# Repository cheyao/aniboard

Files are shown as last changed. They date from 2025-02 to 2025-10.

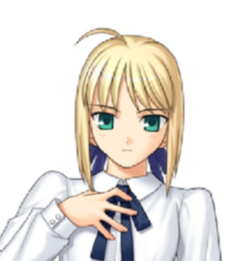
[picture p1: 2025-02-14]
PCB/art/saber-serious.png

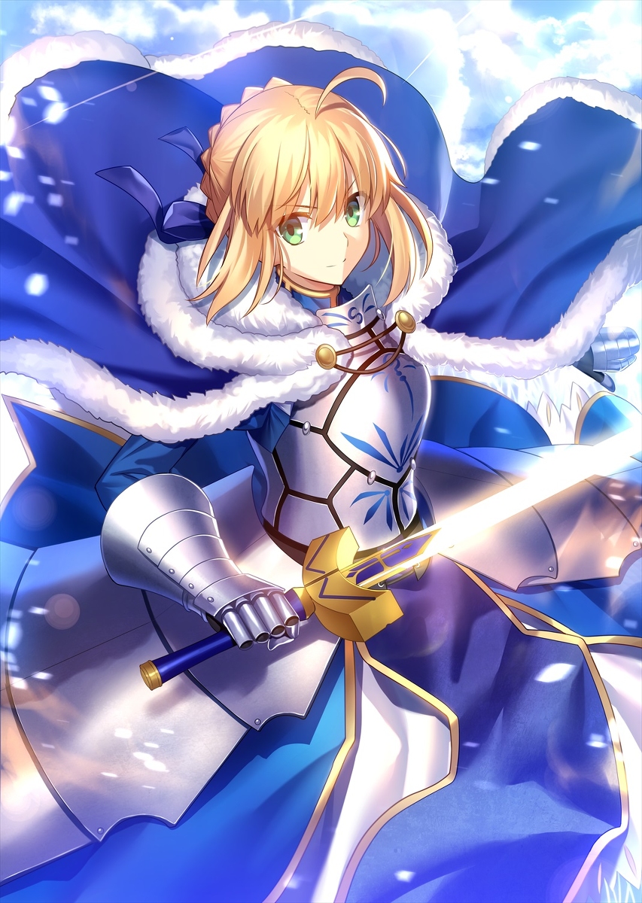
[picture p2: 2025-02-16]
PCB/art/saber-king.jpg

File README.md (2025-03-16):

# Aniboard - Anime themed keyboard

*Insert Final Product Picture*

Made by cyao: `@Cyao` on slack, github.com/cheyao

Features:
- 88x keys!
- Morally correct Alt, Command, Control layout
- 0.91" OLED for your favourite pictures
- 88x Neopixels capable of eating 5.28A! Portable hand warmer :3
- Optional triple USB power input to feed all the hungry neopixels.
- Cute anime silkscreens! (Open PCB in KiCAD and zoom out to find a easter egg :3)
- Adaptive power MUXing and overcurrent fail safes
- Multiple fail safes, optional solder bridge configs
- Super compact design
- Self define tilt (Go edit in `CAD/constants.scad` and regenerate)
- Employes metal electrode leadless face technology to ensure high-reliability and precision with predictable characteristics
- High accuracy, long-term stability, moisture resistance, high-temperature resistance
- Made with precise Hot Air solder reflow technology
- KMK firmware, live edit your keymaps

## PCB 

The PCB's size is 355x120mm

| Schematic |
| - |
|  |

| Two sides |
| - |
|  |

| Front |
| - |
|  |

| Back |
| - |
|  |

3D render pictures:






## Case



The case v1 is fully parametric and made with OpenSCAD, allowed me to make a online case generator. Link after the YSWS ends.

V2 is made with freecad, and is of top mount style.

I chose to not add any engraving since it will look bad. I would want to print my case In school with ams and custom colored fillament when I buy some new fillament. (I need hq to print my case in white for the moment)

## BOM

These were old prices for aliexpress, see bottom for lcsc prices (better)

| Name | Qty | Price (EUR) |
| --- | --- | --- |
| 0.91" OLED SSD1306 | 1 | |
| 0.1uf 0805 capacitors | 90  | |
| 4.7uf 0805 capacitors | 3 | |
| 1uf 0805 capacitor | 3 | |
| MiniMELF diodes | 88  | |
| 0603 GLED Vf2.1 30mA | 7 | |
| USB-C Receptacles | 2 | |
| SK6812MINI-E | 88  | |
| 470Ω 0805 resistor | 5 | |
| 4.7kΩ 0805 resistor | 5 | |
| 5.1kΩ 0805 resistor | 4 | |
| 10kΩ 0805 resistor | 2 | |
| 1kΩ 0805 resistor | 2 | |
| 200Ω 0805 resistor | 3 | |
| TPS2116DRL | 2 | |
| SN74LVC1T45DBVR | 1 | |
| CH224K | 2 | |
| ESP12-E | 1 | |
| Orph/Raspberry Pi Pico | 1 | High Seas |
| Case (Preferably pink, else white "./production/case.3mf") | 1 | Me |
| Acrylic ("./production/acrylic.dxf") | 1 | Hack Club |
| M2 Heatset Inserts 4OD 4mm | 28  | 1.74 |
| M2 Torx Thin Head Bolts 5mm 14mm | 16  | 2.08 |
| M2 Torx Thin Head Bolts 5mm 5mm  | 12  | 1.62 |
| JWK Cupid Switch | 88  | 36.60/w ship|
| 2u MX stabilizor | 5 | 27.99 (20$ new member) |
| 6.25u MX stabilizer | 1 | ^ |

Old:

| Total Price | PCB | Switches | Fasteners | Keycaps  | Stabilizers | Other |
| --- | --- | --- | --- | --- | --- | --- |
| 120.63/ws | 37.00/ws | 38.81/ws | 5.44/ns | 21.79/ws | 19.59/ns | ~24.03/ws |

2$ More in PCB for lead free HASL!

Please add this grant to my High Seas Digikey grant! <3

~The stabs are 22.38 USD so going to transfer 5$ to HQ.~ Done, https://hcb.hackclub.com/hackpad/donations - Chengyin Yao aka Cyao

~Uhh I think the TX are still over budget? Gonna figure something out.~ Found in budget TX! Gonna abuse new member discount lol.

The LCSC cart might seem to have excess of some components, it's either: minimal quanitity, or at the end I could spend 2.7$ more to save 6$ so why not

Cupid: https://keygem.com/products/cupid-switch-group-buy-10pcs?variant=44806087770380

## Notes:

This got me 60h on cafe :sob:

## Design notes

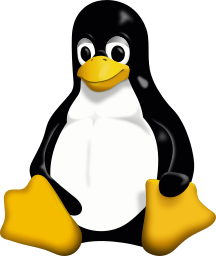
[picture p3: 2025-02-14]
PCB/art/tux.png

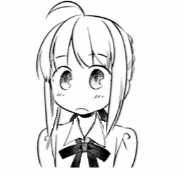
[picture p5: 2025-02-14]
PCB/art/saber-shocked.png

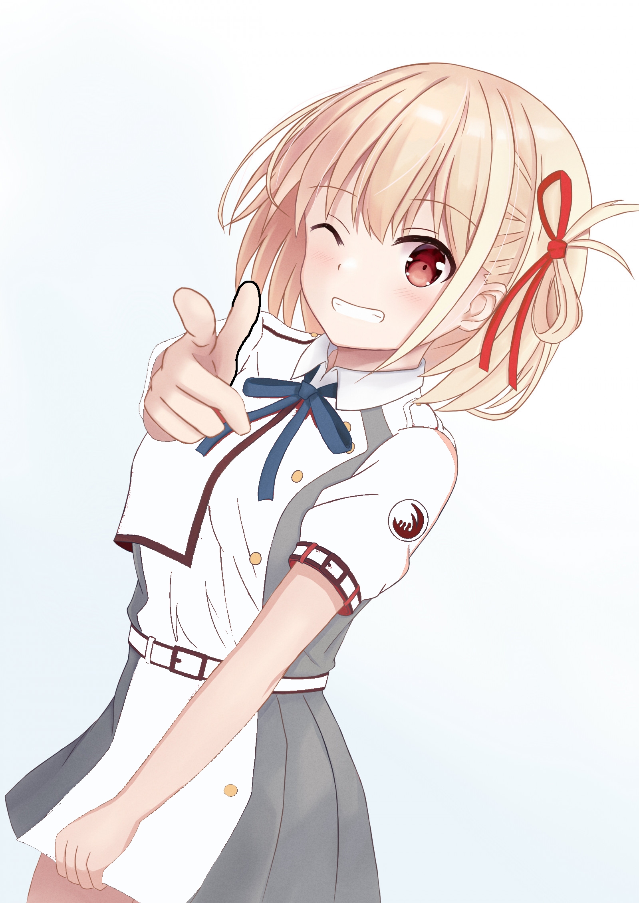
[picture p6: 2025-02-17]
PCB/art/chisato-cute-shooting-edit.jpg

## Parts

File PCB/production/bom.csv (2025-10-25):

Designator | Footprint | Quantity | Value | LCSC Part #
BRD1 | SSD1306-0.91-OLED-4pin-128x32 | 1 | SSD1306
C1, C10, C11, C12, C13, C14, C19, C2, C20, C21, C22, C23, C24, C25, C26, C27, C28, C29, C3, C30, C31, C32, C33, C34, C35, C36, C37, C38, C39, C4, C40, C41, C42, C43, C44, C45, C46, C47, C48, C49, C5, C50, C51, C52, C54, C55, C56, C57, C58, C59, C6, C60, C61, C62, C63, C64, C65, C66, C67, C68, C69, C7, C70, C71, C72, C73, C74, C75, C76, C77, C78, C79, C8, C80, C81, C82, C83, C84, C85, C86, C87, C88, C89, C9, C90, C91, C92, C93, C95, C96 | 0805 | 90 | 0.1uf
C18, C94 | 0805 | 2 | 1uf
D1, D10, D11, D12, D13, D14, D16, D17, D18, D19, D2, D20, D21, D22, D23, D24, D25, D26, D27, D28, D29, D3, D30, D31, D32, D33, D34, D35, D36, D37, D38, D39, D4, D40, D41, D42, D43, D44, D45, D46, D47, D48, D49, D5, D50, D51, D52, D53, D54, D55, D56, D57, D58, D59, D6, D60, D61, D62, D63, D64, D65, D67, D68, D69, D7, D70, D71, D72, D73, D74, D75, D76, D77, D78, D79, D8, D80, D81, D82, D83, D84, D85, D86, D87, D88, D89, D9, D90 | D_MiniMELF_Handsoldering | 88 | D
D91, D92, D93, D95 | 0603 | 4 | LED
J1 | PinSocket_1x02_P2.54mm_Vertical | 1 | Conn_01x02_Pin
J5 | PinHeader_1x03_P2.54mm_Vertical | 1 | Conn_01x03_Pin
J6 | USB_C_Receptacle_GCT_USB4105-xx-A_16P_TopMnt_Horizontal | 1 | USB_C_Receptacle_USB2.0_14P
LED1, LED10, LED11, LED12, LED13, LED14, LED2, LED3, LED32, LED33, LED34, LED35, LED36, LED37, LED38, LED39, LED4, LED40, LED41, LED42, LED43, LED44, LED45, LED46, LED47, LED48, LED5, LED6, LED65, LED66, LED67, LED68, LED69, LED7, LED70, LED71, LED72, LED73, LED74, LED75, LED76, LED77, LED8, LED9 | LED_MX_6028R | 44 | MX_SK6812MINI-E
LED15, LED16, LED17, LED18, LED19, LED20, LED21, LED22, LED23, LED24, LED25, LED26, LED27, LED28, LED29, LED30, LED31, LED49, LED50, LED51, LED52, LED53, LED54, LED55, LED56, LED57, LED58, LED59, LED60, LED61, LED62, LED63, LED64, LED78, LED79, LED80, LED81, LED82, LED83, LED84, LED85, LED86, LED87, LED88 | LED_MX_6028R-ROT | 44 | MX_SK6812MINI-E
R10, R11, R21 | 0805 | 3 | 4.7kΩ
R12, R13, R9 | 0805 | 3 | 470Ω
R14 | 0805 | 1 | 10kΩ
R15 | 0805 | 1 | 1kΩ
R16, R20 | 0805 | 2 | 200Ω
S1 | STAB_MX_P_2u | 1 | MX_stab
S2, S3 | STAB_MX_P_2.25u | 2 | MX_stab
S4 | STAB_MX_P_2.75u | 1 | MX_stab
S5 | STAB_MX_P_6.25u | 1 | MX_stab
SW1, SW14, SW32, SW45 | SW_MX_1.5u | 4 | SW_Push
SW10, SW11, SW12, SW13, SW15, SW16, SW17, SW18, SW19, SW2, SW20, SW21, SW22, SW23, SW24, SW25, SW26, SW27, SW28, SW29, SW3, SW30, SW31, SW33, SW34, SW35, SW36, SW37, SW38, SW39, SW4, SW40, SW41, SW42, SW43, SW44, SW46, SW47, SW48, SW5, SW50, SW51, SW52, SW53, SW54, SW55, SW56, SW57, SW58, SW59, SW6, SW60, SW61, SW62, SW63, SW64, SW65, SW66, SW67, SW68, SW69, SW7, SW70, SW71, SW72, SW73, SW74, SW75, SW76, SW77, SW8, SW81, SW86, SW87, SW88, SW9 | SW_MX_1u | 76 | SW_Push
SW49 | SW_MX_1.75u | 1 | SW_Push
SW78, SW79, SW80, SW82, SW83, SW84, SW85 | SW_MX_1.25u | 7 | SW_Push
TP1, TP2, TP4, TP5, TP6 | TestPoint_Pad_D3.0mm | 5 | TestPoint
U3 | SOT-23-6 | 1 | SN74LVC1T45DBV
U4 | RPi_Pico_SMD_TH | 1 | Pico
U5 | SSOP-10-1EP_3.9x4.9mm_P1mm_EP2.1x3.3mm | 1 | CH224K
U7 | ESP-12E | 1 | ESP-12E

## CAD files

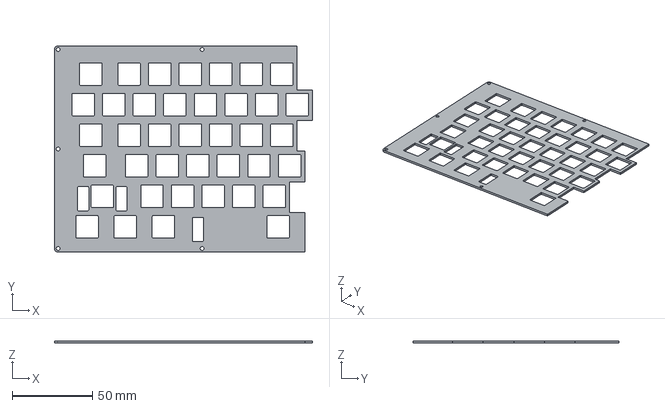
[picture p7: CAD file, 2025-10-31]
CAD/case-CaseSlice.0.step
160.8 x 128.5 x 1.50 mm

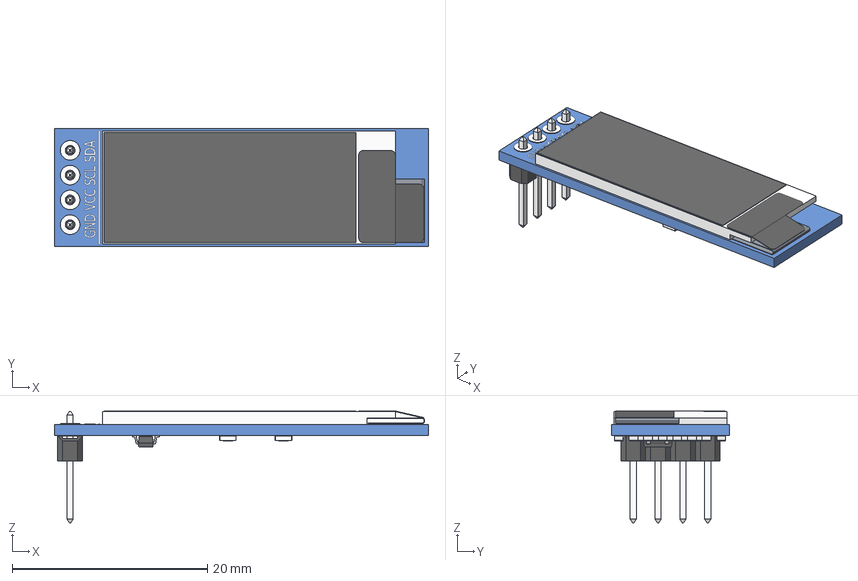
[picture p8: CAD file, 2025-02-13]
PCB/KiCad-SSD1306-128x64-master/oled_0.91_128x32.step
38.3 x 12.1 x 11.5 mm
OLED_0.91_128x32
Pin Header 4 x 1 TH 2.54mm Pitch
RESC-0603 x 13
2SD0601A

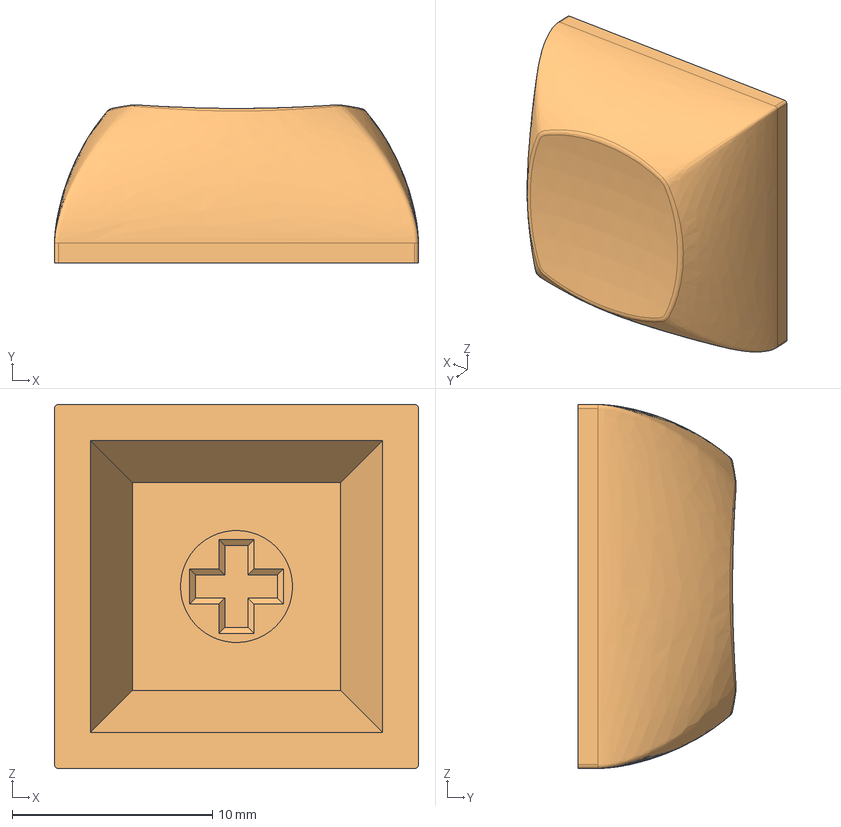
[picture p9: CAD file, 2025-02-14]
PCB/models/DSA 1u.step
18.2 x 7.91 x 18.2 mm

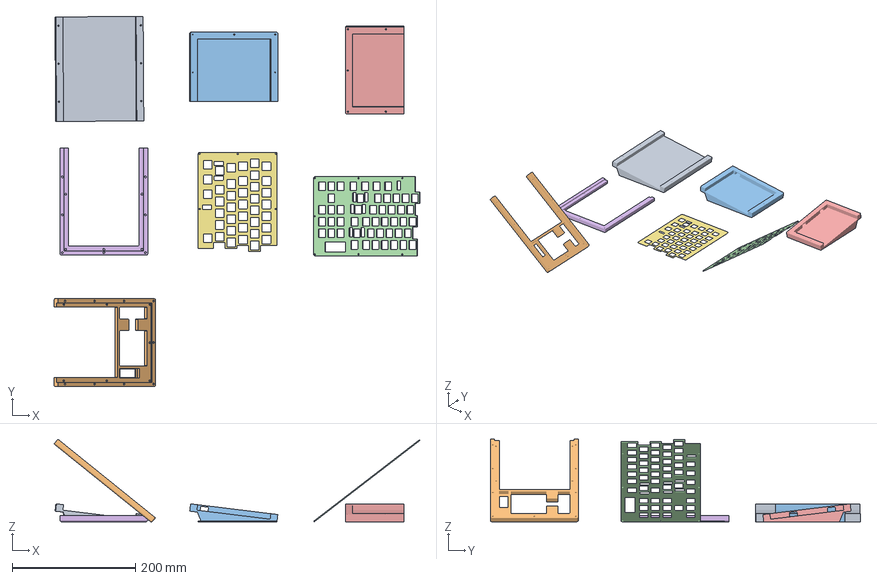
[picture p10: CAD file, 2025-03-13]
CAD/case.3mf
595.1 x 602.0 x 134.6 mm

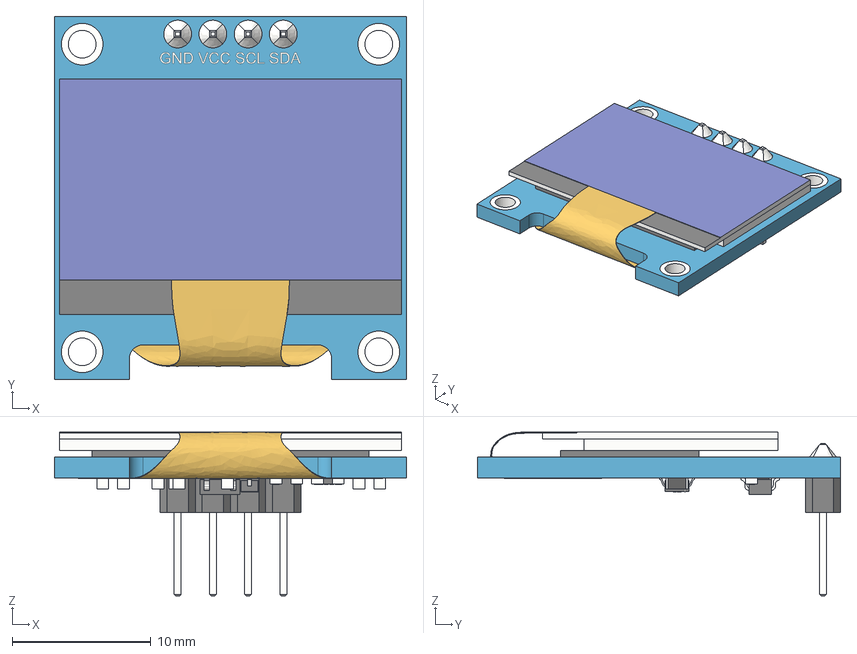
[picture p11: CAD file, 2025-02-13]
PCB/KiCad-SSD1306-128x64-master/SSD1306_OLED_Display(128x64).step
25.4 x 26.2 x 11.8 mm
board
screen
pin_header
soldering
smd_capacitor
smd_capacitor (1)
914_smd_resistor
472_smd_resistor x 3
t4_smd_diode
smd_capacitor (2)
smd_capacitor (3)
smd_capacitor (4)
smd_capacitor (5)
smd_capacitor (6)
472_smd_resistor (1)
SOT-23_XC6206 v3
smd_capacitor (7)
flat_cable

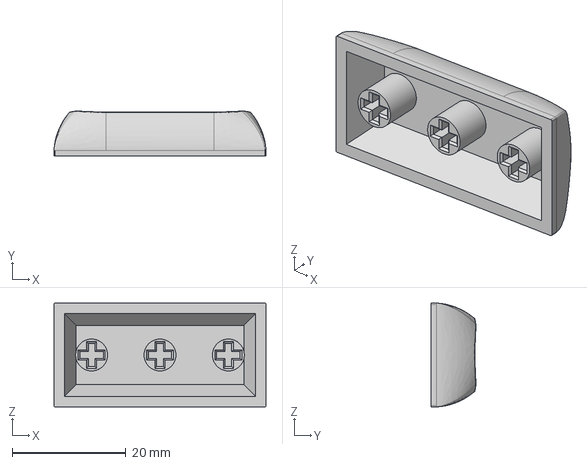
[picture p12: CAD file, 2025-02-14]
PCB/models/DSA 2u.step
37.2 x 7.91 x 18.2 mm

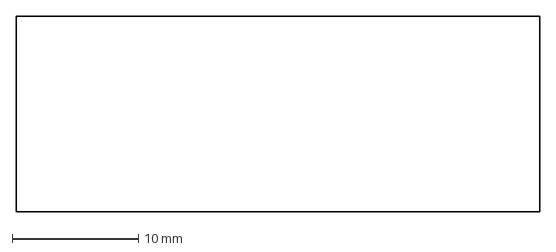
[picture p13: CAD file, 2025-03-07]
CAD/acrylic.dxf
41.5 x 15.5 mm

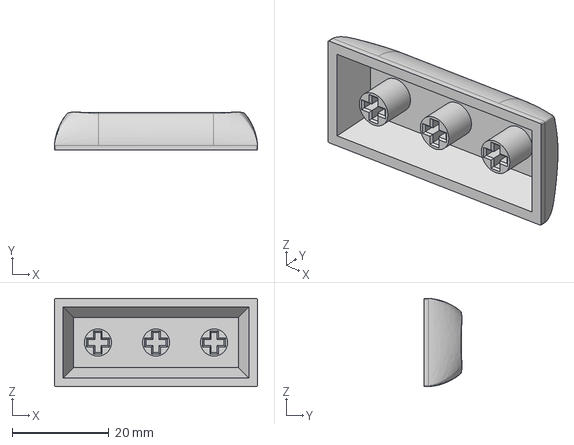
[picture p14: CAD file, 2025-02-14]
PCB/models/DSA 2.25u.step
42.0 x 7.91 x 18.2 mm

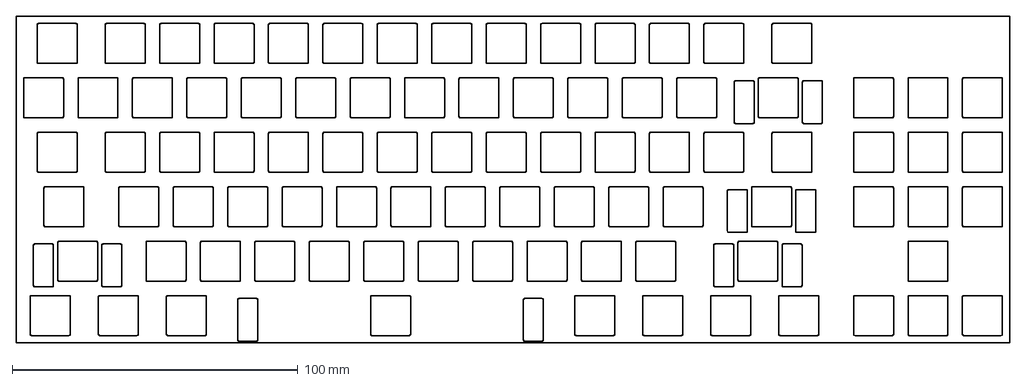
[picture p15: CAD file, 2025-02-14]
CAD/plate.dxf
347.7 x 114.3 mm

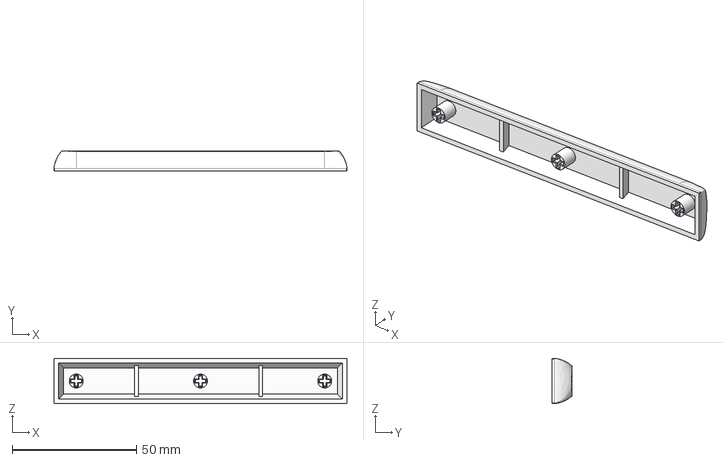
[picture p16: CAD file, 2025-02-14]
PCB/models/DSA Spacebar 6.25u (50mm spacing).step
118.0 x 8.00 x 18.2 mm

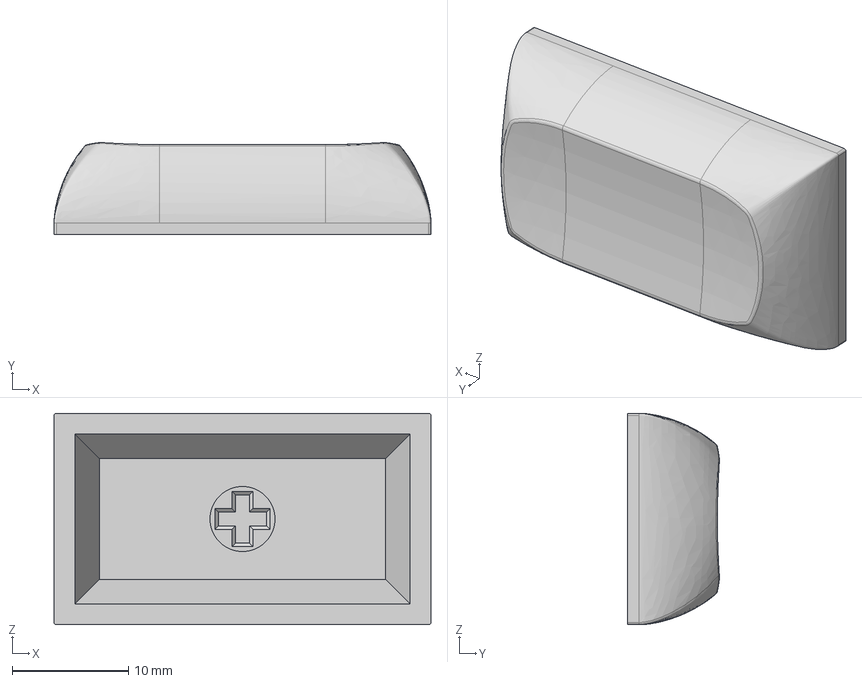
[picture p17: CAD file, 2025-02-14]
PCB/models/DSA 1.75u.step
32.5 x 7.91 x 18.2 mm

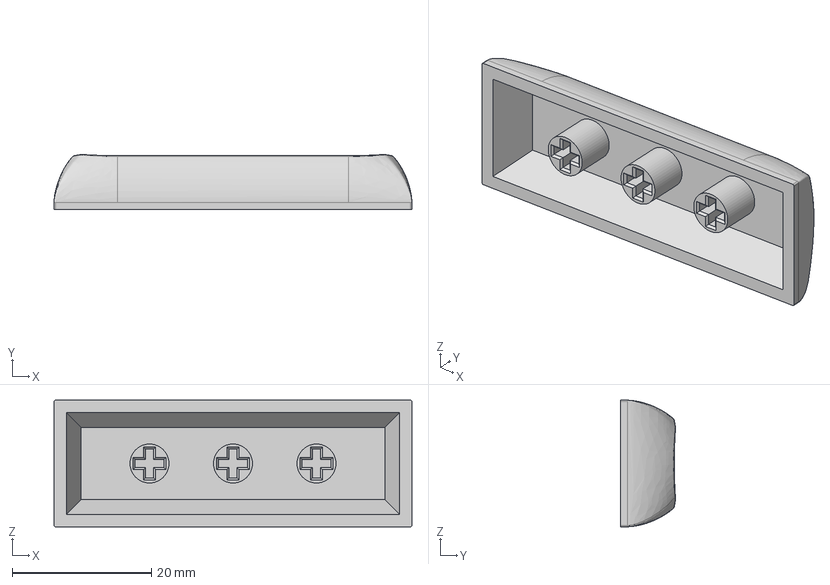
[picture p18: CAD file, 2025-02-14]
PCB/models/DSA 2.75u.step
51.5 x 7.91 x 18.2 mm

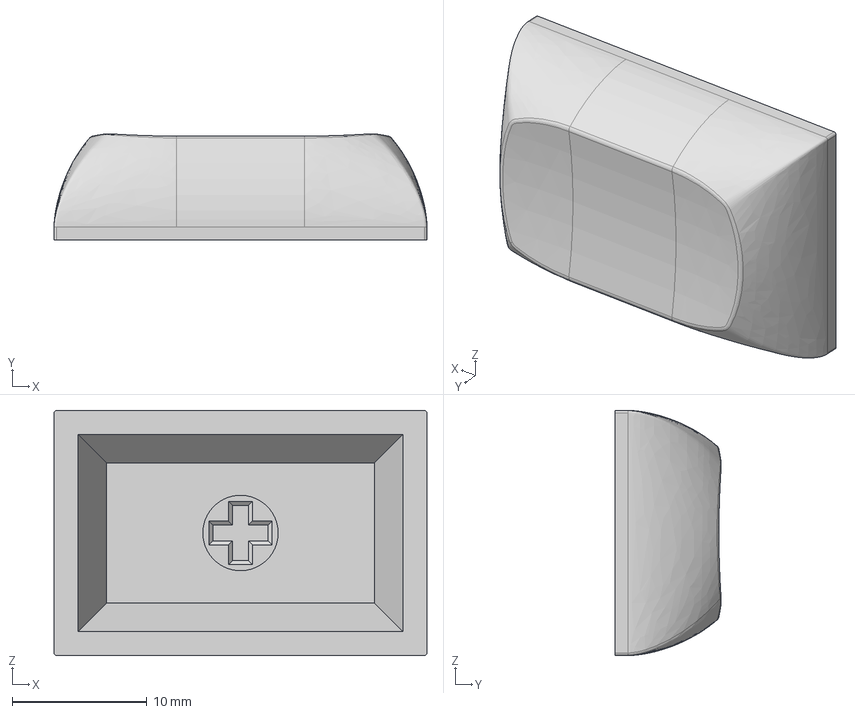
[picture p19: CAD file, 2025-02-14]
PCB/models/DSA 1.5u.step
27.7 x 7.91 x 18.2 mm

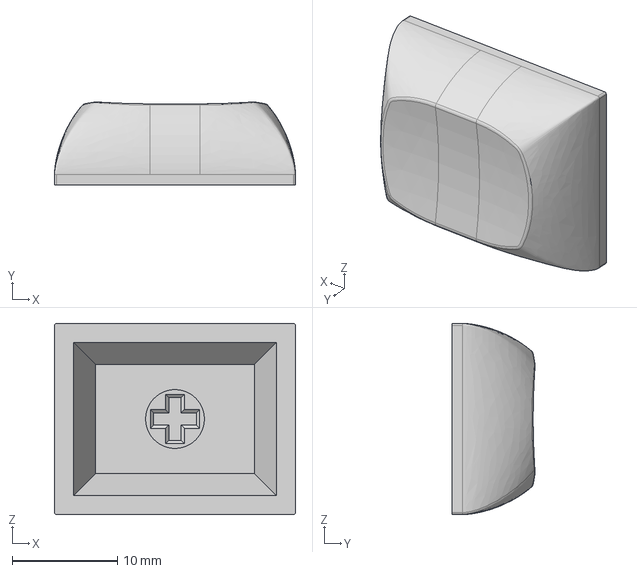
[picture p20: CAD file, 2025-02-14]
PCB/models/DSA 1.25u.step
22.9 x 7.91 x 18.2 mm

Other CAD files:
production/case.3mf
production/acrylic.dxf
PCB/models/SW_Cherry_MX_PCB.stp
CAD/archive/assembly.stl
CAD/archive/case.scad
CAD/archive/common.scad
CAD/archive/plate.scad
CAD/archive/BOSL/constants.scad
CAD/archive/BOSL/acme_screws.scad
CAD/archive/BOSL/beziers.scad
CAD/archive/BOSL/compat.scad
CAD/archive/BOSL/convex_hull.scad
CAD/archive/BOSL/debug.scad
CAD/archive/BOSL/examples/bezier_patches.scad
CAD/archive/BOSL/examples/orientations.scad
CAD/archive/BOSL/involute_gears.scad
CAD/archive/BOSL/joiners.scad
CAD/archive/BOSL/linear_bearings.scad
CAD/archive/BOSL/masks.scad
CAD/archive/BOSL/math.scad
CAD/archive/BOSL/metric_screws.scad
CAD/archive/BOSL/nema_steppers.scad
CAD/archive/BOSL/paths.scad
CAD/archive/BOSL/phillips_drive.scad
CAD/archive/BOSL/quaternions.scad
CAD/archive/BOSL/shapes.scad
CAD/archive/BOSL/sliders.scad
CAD/archive/BOSL/tests/test_convex_hull.scad
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

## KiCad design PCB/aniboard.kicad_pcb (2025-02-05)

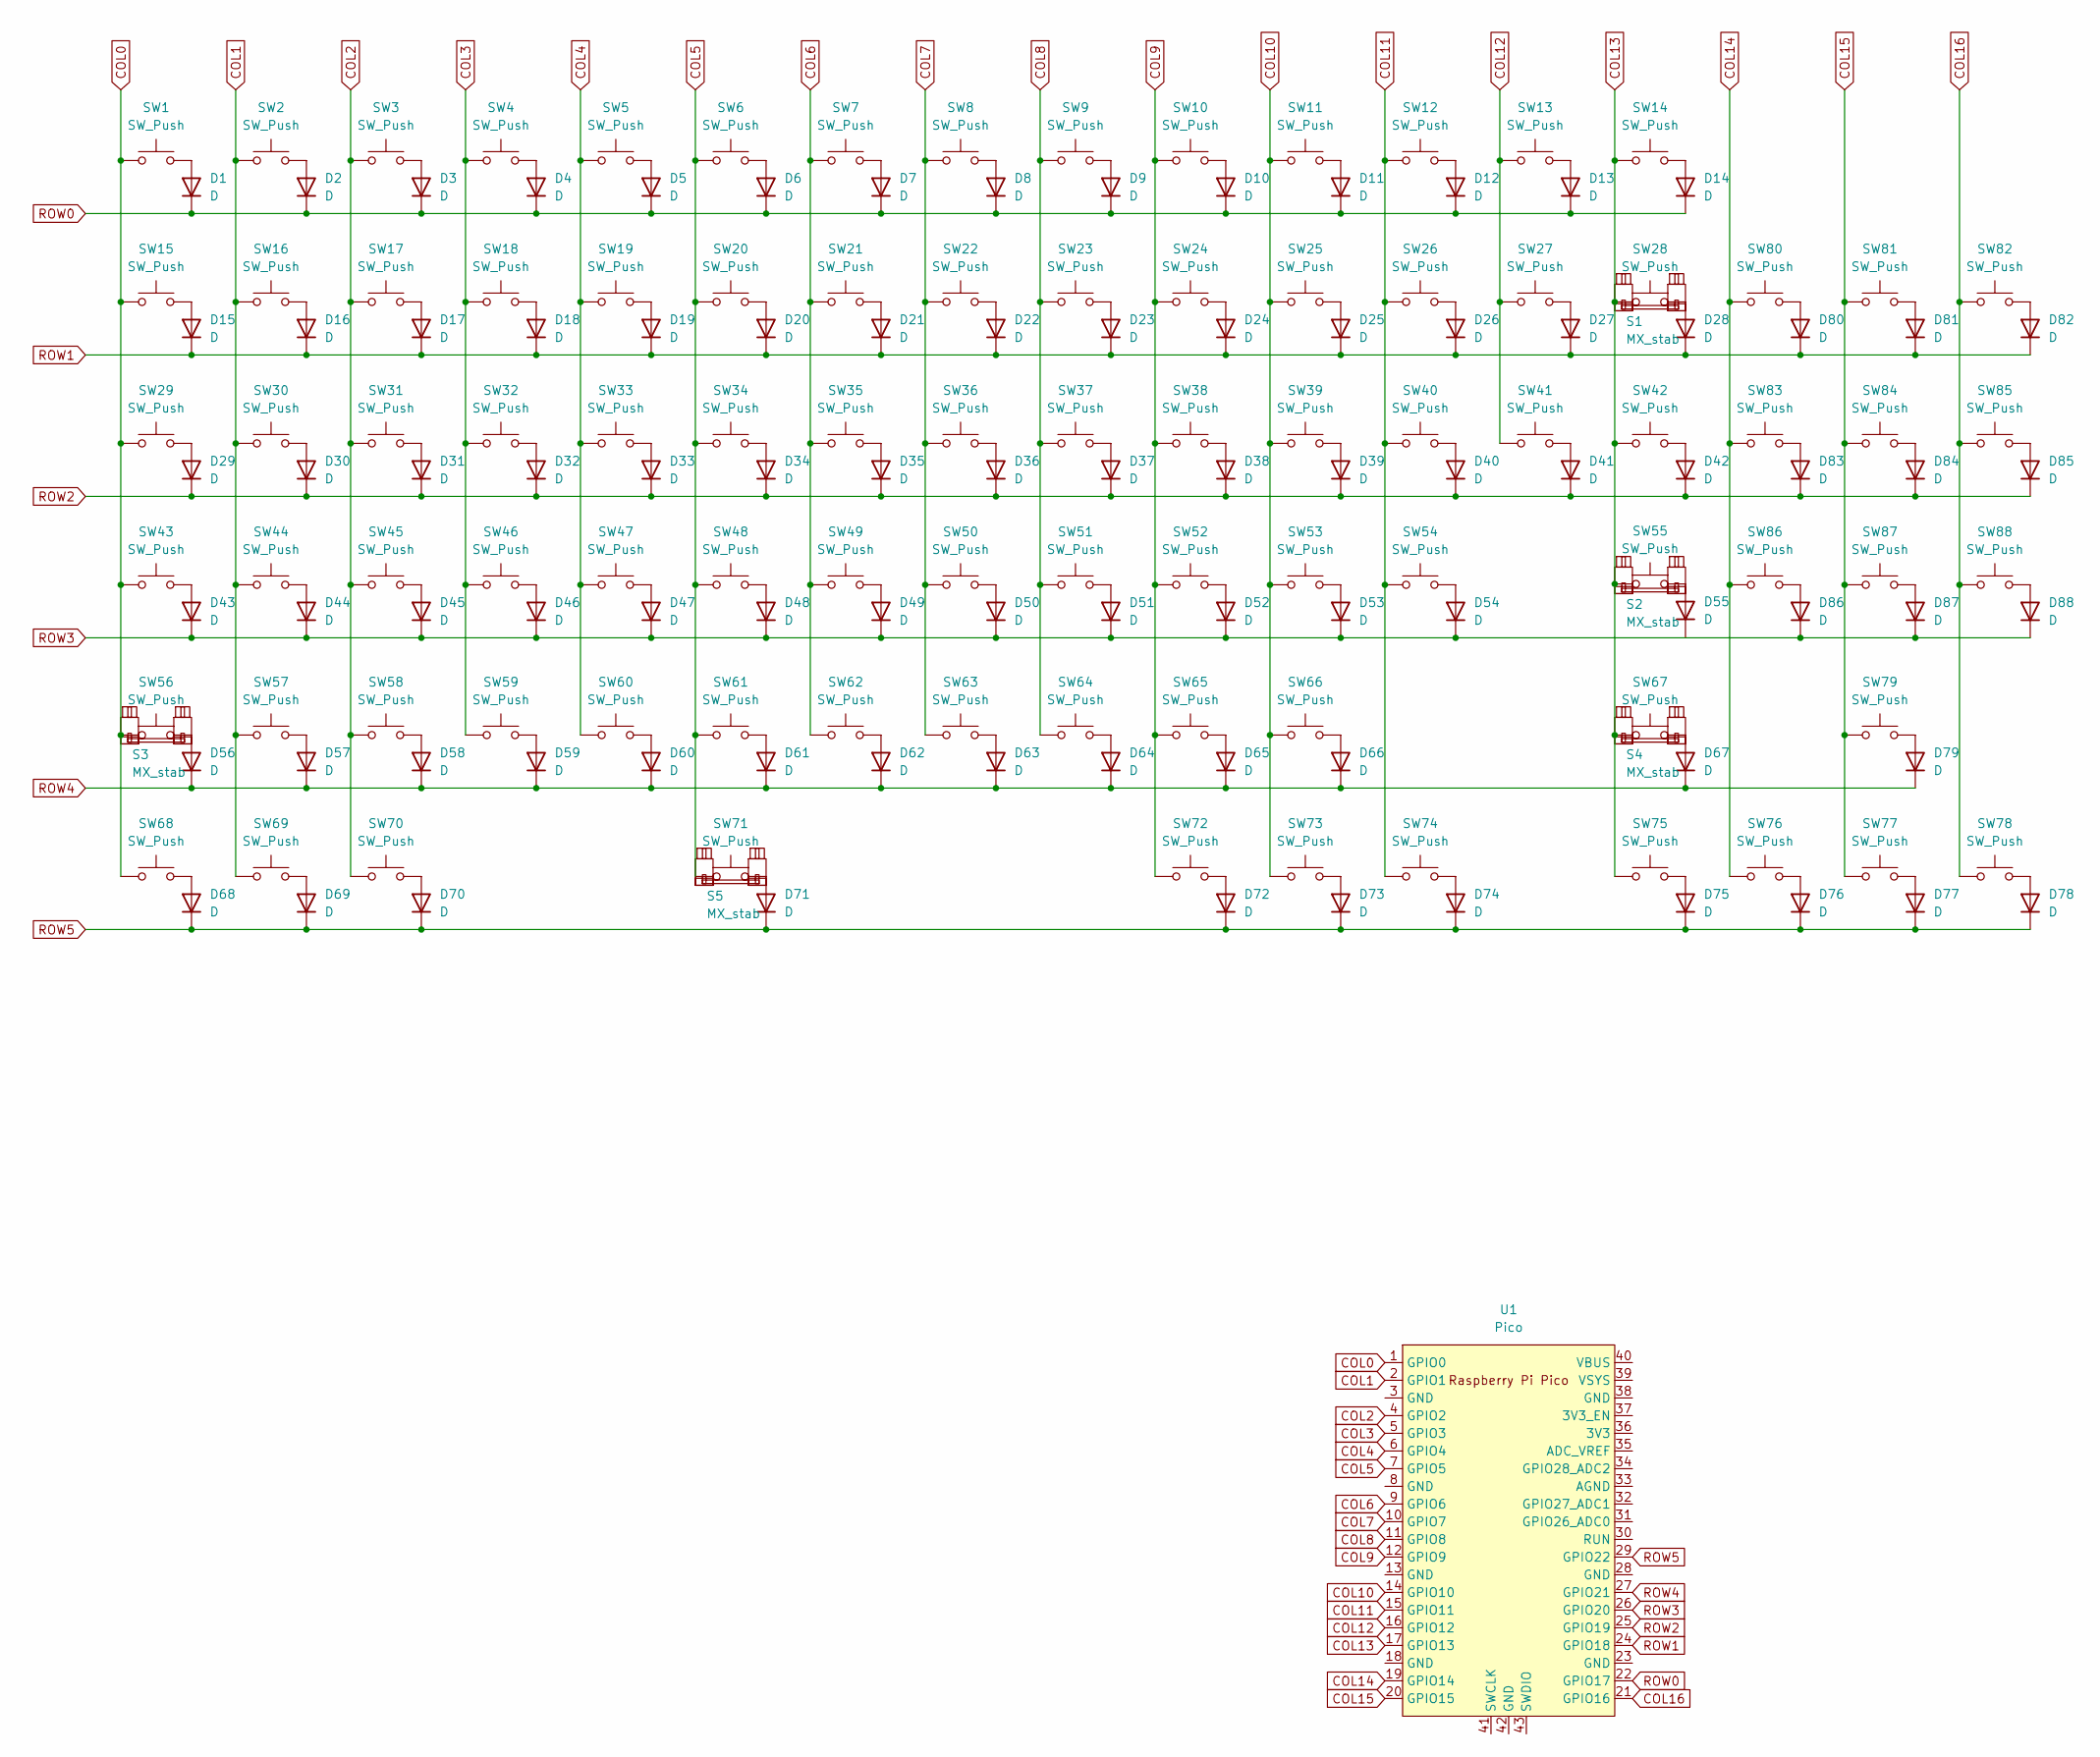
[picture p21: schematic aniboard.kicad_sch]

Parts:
D1, D2, D3, D4, D5, D6, D7, D8, D9, D10, D11, D12, D13, D14, D15, D16, D17, D18, D19, D20, D21, D22, D23, D24, D25, D26, D27, D28, D29, D30, D31, D32, D33, D34, D35, D36, D37, D38, D39, D40, D41, D42, D43, D44, D45, D46, D47, D48, D49, D50, D51, D52, D53, D54, D55, D56, D57, D58, D59, D60, D61, D62, D63, D64, D65, D66, D67, D68, D69, D70, D71, D72, D73, D74, D75, D76, D77, D78, D79, D80, D81, D82, D83, D84, D85, D86, D87, D88: D; D_DO-35_SOD27_P7.62mm_Horizontal
S1: MX_stab; STAB_MX_2u
S2, S3: MX_stab; STAB_MX_2.25u
S4: MX_stab; STAB_MX_2.75u
S5: MX_stab; STAB_MX_6.25u
SW1, SW14, SW29, SW42: SW_Push; SW_MX_1.5u
SW2, SW3, SW4, SW5, SW6, SW7, SW8, SW9, SW10, SW11, SW12, SW13, SW15, SW16, SW17, SW18, SW19, SW20, SW21, SW22, SW23, SW24, SW25, SW26, SW27, SW28, SW30, SW31, SW32, SW33, SW34, SW35, SW36, SW37, SW38, SW39, SW40, SW41, SW44, SW45, SW46, SW47, SW48, SW49, SW50, SW51, SW52, SW53, SW54, SW55, SW56, SW57, SW58, SW59, SW60, SW61, SW62, SW63, SW64, SW65, SW66, SW67, SW71, SW76, SW77, SW78, SW79, SW80, SW81, SW82, SW83, SW84, SW85, SW86, SW87, SW88: SW_Push; SW_MX_1u
SW43: SW_Push; SW_MX_1.75u
SW68, SW69, SW70, SW72, SW73, SW74, SW75: SW_Push; SW_MX_1.25u
U1: Pico; RPi_Pico_SMD_TH

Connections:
COL0: SW1.1, SW15.1, SW29.1, SW43.1, SW56.1, SW68.1, U1.1 (GPIO0)
COL1: SW2.1, SW16.1, SW30.1, SW44.1, SW57.1, SW69.1, U1.2 (GPIO1)
COL2: SW3.1, SW17.1, SW31.1, SW45.1, SW58.1, SW70.1, U1.4 (GPIO2)
COL3: SW4.1, SW18.1, SW32.1, SW46.1, SW59.1, U1.5 (GPIO3)
COL4: SW5.1, SW19.1, SW33.1, SW47.1, SW60.1, U1.6 (GPIO4)
COL5: SW6.1, SW20.1, SW34.1, SW48.1, SW61.1, SW71.1, U1.7 (GPIO5)
COL6: SW7.1, SW21.1, SW35.1, SW49.1, SW62.1, U1.9 (GPIO6)
COL7: SW8.1, SW22.1, SW36.1, SW50.1, SW63.1, U1.10 (GPIO7)
COL8: SW9.1, SW23.1, SW37.1, SW51.1, SW64.1, U1.11 (GPIO8)
COL9: SW10.1, SW24.1, SW38.1, SW52.1, SW65.1, SW72.1, U1.12 (GPIO9)
COL10: SW11.1, SW25.1, SW39.1, SW53.1, SW66.1, SW73.1, U1.14 (GPIO10)
COL11: SW12.1, SW26.1, SW40.1, SW54.1, SW74.1, U1.15 (GPIO11)
COL12: SW13.1, SW27.1, SW41.1, U1.16 (GPIO12)
COL13: SW14.1, SW28.1, SW42.1, SW55.1, SW67.1, SW75.1, U1.17 (GPIO13)
COL14: SW76.1, SW80.1, SW83.1, SW86.1, U1.19 (GPIO14)
COL15: SW77.1, SW79.1, SW81.1, SW84.1, SW87.1, U1.20 (GPIO15)
COL16: SW78.1, SW82.1, SW85.1, SW88.1, U1.21 (GPIO16)
unnamed: D1.2 (A), SW1.2
unnamed: D2.2 (A), SW2.2
unnamed: D3.2 (A), SW3.2
unnamed: D4.2 (A), SW4.2
unnamed: D5.2 (A), SW5.2
unnamed: D6.2 (A), SW6.2
unnamed: D7.2 (A), SW7.2
unnamed: D8.2 (A), SW8.2
unnamed: D9.2 (A), SW9.2
unnamed: D10.2 (A), SW10.2
unnamed: D11.2 (A), SW11.2
unnamed: D12.2 (A), SW12.2
unnamed: D13.2 (A), SW13.2
unnamed: D14.2 (A), SW14.2
unnamed: D15.2 (A), SW15.2
unnamed: D16.2 (A), SW16.2
unnamed: D17.2 (A), SW17.2
unnamed: D18.2 (A), SW18.2
unnamed: D19.2 (A), SW19.2
unnamed: D20.2 (A), SW20.2
unnamed: D21.2 (A), SW21.2
unnamed: D22.2 (A), SW22.2
unnamed: D23.2 (A), SW23.2
unnamed: D24.2 (A), SW24.2
unnamed: D25.2 (A), SW25.2
unnamed: D26.2 (A), SW26.2
unnamed: D27.2 (A), SW27.2
unnamed: D28.2 (A), SW28.2
unnamed: D29.2 (A), SW29.2
unnamed: D30.2 (A), SW30.2
unnamed: D31.2 (A), SW31.2
unnamed: D32.2 (A), SW32.2
unnamed: D33.2 (A), SW33.2
unnamed: D34.2 (A), SW34.2
unnamed: D35.2 (A), SW35.2
unnamed: D36.2 (A), SW36.2
unnamed: D37.2 (A), SW37.2
unnamed: D38.2 (A), SW38.2
unnamed: D39.2 (A), SW39.2
unnamed: D40.2 (A), SW40.2
unnamed: D41.2 (A), SW41.2
unnamed: D42.2 (A), SW42.2
unnamed: D43.2 (A), SW43.2
unnamed: D44.2 (A), SW44.2
unnamed: D45.2 (A), SW45.2
unnamed: D46.2 (A), SW46.2
unnamed: D47.2 (A), SW47.2
unnamed: D48.2 (A), SW48.2
unnamed: D49.2 (A), SW49.2
unnamed: D50.2 (A), SW50.2
unnamed: D51.2 (A), SW51.2
unnamed: D52.2 (A), SW52.2
unnamed: D53.2 (A), SW53.2
unnamed: D54.2 (A), SW54.2
unnamed: D55.2 (A), SW55.2
unnamed: D56.2 (A), SW56.2
unnamed: D57.2 (A), SW57.2
unnamed: D58.2 (A), SW58.2
unnamed: D59.2 (A), SW59.2
unnamed: D60.2 (A), SW60.2
unnamed: D61.2 (A), SW61.2
unnamed: D62.2 (A), SW62.2
unnamed: D63.2 (A), SW63.2
unnamed: D64.2 (A), SW64.2
unnamed: D65.2 (A), SW65.2
unnamed: D66.2 (A), SW66.2
unnamed: D67.2 (A), SW67.2
unnamed: D68.2 (A), SW68.2
unnamed: D69.2 (A), SW69.2
unnamed: D70.2 (A), SW70.2
unnamed: D71.2 (A), SW71.2
unnamed: D72.2 (A), SW72.2
unnamed: D73.2 (A), SW73.2
unnamed: D74.2 (A), SW74.2
unnamed: D75.2 (A), SW75.2
unnamed: D76.2 (A), SW76.2
unnamed: D77.2 (A), SW77.2
unnamed: D78.2 (A), SW78.2
unnamed: D79.2 (A), SW79.2
unnamed: D80.2 (A), SW80.2
unnamed: D81.2 (A), SW81.2
unnamed: D82.2 (A), SW82.2
unnamed: D83.2 (A), SW83.2
unnamed: D84.2 (A), SW84.2
unnamed: D85.2 (A), SW85.2
unnamed: D86.2 (A), SW86.2
unnamed: D87.2 (A), SW87.2
unnamed: D88.2 (A), SW88.2
ROW0: D1.1 (K), D2.1 (K), D3.1 (K), D4.1 (K), D5.1 (K), D6.1 (K), D7.1 (K), D8.1 (K), D9.1 (K), D10.1 (K), D11.1 (K), D12.1 (K), D13.1 (K), D14.1 (K), U1.22 (GPIO17)
ROW1: D15.1 (K), D16.1 (K), D17.1 (K), D18.1 (K), D19.1 (K), D20.1 (K), D21.1 (K), D22.1 (K), D23.1 (K), D24.1 (K), D25.1 (K), D26.1 (K), D27.1 (K), D28.1 (K), D80.1 (K), D81.1 (K), D82.1 (K), U1.24 (GPIO18)
ROW2: D29.1 (K), D30.1 (K), D31.1 (K), D32.1 (K), D33.1 (K), D34.1 (K), D35.1 (K), D36.1 (K), D37.1 (K), D38.1 (K), D39.1 (K), D40.1 (K), D41.1 (K), D42.1 (K), D83.1 (K), D84.1 (K), D85.1 (K), U1.25 (GPIO19)
ROW3: D43.1 (K), D44.1 (K), D45.1 (K), D46.1 (K), D47.1 (K), D48.1 (K), D49.1 (K), D50.1 (K), D51.1 (K), D52.1 (K), D53.1 (K), D54.1 (K), D86.1 (K), D87.1 (K), D88.1 (K), U1.26 (GPIO20)
ROW4: D56.1 (K), D57.1 (K), D58.1 (K), D59.1 (K), D60.1 (K), D61.1 (K), D62.1 (K), D63.1 (K), D64.1 (K), D65.1 (K), D66.1 (K), D67.1 (K), D79.1 (K), U1.27 (GPIO21)
ROW5: D68.1 (K), D69.1 (K), D70.1 (K), D71.1 (K), D72.1 (K), D73.1 (K), D74.1 (K), D75.1 (K), D76.1 (K), D77.1 (K), D78.1 (K), U1.29 (GPIO22)

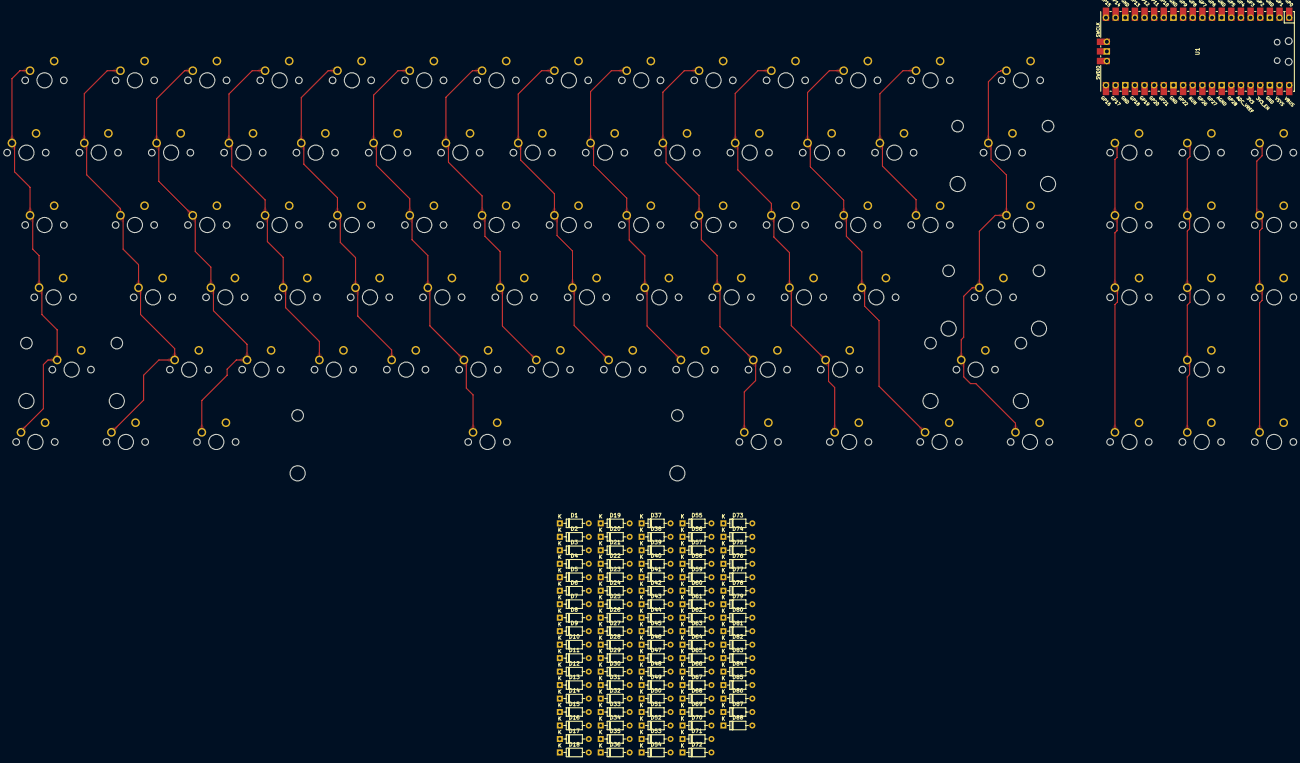
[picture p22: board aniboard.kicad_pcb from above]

Board: 2 copper layers, 182 parts (0 on the bottom side), 111 nets.

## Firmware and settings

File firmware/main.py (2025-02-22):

# Cyao macropad firmware
# Rev 1.1
# Copyright 2024
# Licensed under zlib license
import board
import busio
import time
import board
from rainbowio import colorwheel

from kmk.kmk_keyboard import KMKKeyboard
from kmk.keys import KC
from kmk.scanners import DiodeOrientation
from kmk.modules.macros import Macros
from kmk.extensions.display import Display, TextEntry, ImageEntry
from kmk.extensions.display.ssd1306 import SSD1306
from kmk.extensions.RGB import RGB
from kmk.extensions.rgb import AnimationModes
from kmk.extensions.media_keys import MediaKeys
from kmk.modules.mouse_keys import MouseKeys
from kmk.modules.layers import Layers

LED_PIN = board.D10;

bus = busio.I2C(board.SCL, board.SDA);
driver = SSD1306(i2c=bus, device_address=0x3C);
display = Display(
    display=driver,
    width=128,
    height=64,
    dim_time=10,
    dim_target=0.2,
    off_time=1200,
    brightness=0.7
);
display.entries = [
    ImageEntry(image="pic.bmp", x=0, y=0),
];

keyboard = KMKKeyboard();

macros = Macros();
keyboard.extensions.append(display);
keyboard.extensions.append(MediaKeys())
keyboard.modules.append(macros);
keyboard.modules.append(MouseKeys())
keyboard.modules.append(Layers())

keyboard.col_pins = (board.D16, board.D17, board.D18, board.D19, board.D20, board.D21, board.D22, board.D26, board.D27, board.D11, board.D12, board.D13, board.D14, board.D10, board.D9, board.D8, board.D3);
keyboard.row_pins = (board.D15, board.D2, board.D1, board.D0, board.D7, board.D6);
keyboard.diode_orientation = DiodeOrientation.COL2ROW;

rgb = RGB(pixel_pin=board.D28, num_pixels=4, animation_speed=1, animation_mode=AnimationModes.SWIRL, val_default=30, val_limit=40)
keyboard.extensions.append(rgb)

keyboard.keymap = [
    [
        KC.ESC , KC.MUTE, KC.VOLD, KC.VOLU, KC.MPRV, KC.MSTP, KC.MNXT, KC.BRID, KC.BRIU, KC.NO  , KC.NO  , KC.NO  , KC.NO  , KC.DEL , KC.NO  , KC.NO  , KC.NO  ,
        KC.GRV , KC.N1  , KC.N2  , KC.N3  , KC.N4  , KC.N5  , KC.N6  , KC.N7  , KC.N8  , KC.N9  , KC.N0  , KC.MINS, KC.EQL , KC.BSPC, KC.NO  , KC.NO  , KC.NO  ,
        KC.TAB , KC.Q   , KC.W   , KC.E   , KC.R   , KC.T   , KC.Y   , KC.U   , KC.I   , KC.O   , KC.P   , KC.LBRC, KC.RBTC, KC.BSLS, KC.NO  , KC.NO  , KC.NO  ,
        KC.ESC , KC.A   , KC.S   , KC.D   , KC.F   , KC.G   , KC.H   , KC.J   , KC.K   , KC.L   , KC.SCLN, KC.QUOT, KC.ENT , KC.NO  , KC.NO  , KC.NO  , KC.NO  ,
        KC.LSFT, KC.Z   , KC.X   , KC.C   , KC.V   , KC.B   , KC.N   , KC.M   , KC.COMM, KC.DOT , KC.SLSH, KC.NO  , KC.NO  , KC.RSFT, KC.NO  , KC.UP  , KC.NO  ,
        KC.LALT, KC.LCMD, KC.LCTL, KC.NO  , KC.NO  , KC.SPC , KC.NO  , KC.NO  , KC.NO  , KC.RCTL, KC.RCMD, KC.MO(1), KC.NO  , KC.NO  , KC.LEFT, KC.DOWN, KC.RGHT, 
    ],

    # Function keys
    [
        KC.ESC , KC.F1  , KC.F2  , KC.F3  , KC.F4  , KC.F5  , KC.F6  , KC.F7  , KC.F8  , KC.F9  , KC.F10 , KC.F11 , KC.F12 , KC.TRNS, KC.TRNS, KC.TRNS, KC.TRNS, 
        KC.TRNS, KC.TRNS, KC.TRNS, KC.TRNS, KC.TRNS, KC.TRNS, KC.TRNS, KC.TRNS, KC.TRNS, KC.TRNS, KC.TRNS, KC.TRNS, KC.TRNS, KC.TRNS, KC.TRNS, KC.TRNS, KC.TRNS, 
        KC.TRNS, KC.TRNS, KC.TRNS, KC.TRNS, KC.TRNS, KC.TRNS, KC.TRNS, KC.TRNS, KC.TRNS, KC.TRNS, KC.TRNS, KC.TRNS, KC.TRNS, KC.TRNS, KC.TRNS, KC.TRNS, KC.TRNS, 
        KC.TRNS, KC.TRNS, KC.TRNS, KC.TRNS, KC.TRNS, KC.TRNS, KC.TRNS, KC.TRNS, KC.TRNS, KC.TRNS, KC.TRNS, KC.TRNS, KC.TRNS, KC.TRNS, KC.TRNS, KC.TRNS, KC.TRNS, 
        KC.TRNS, KC.TRNS, KC.TRNS, KC.TRNS, KC.TRNS, KC.TRNS, KC.TRNS, KC.TRNS, KC.TRNS, KC.TRNS, KC.TRNS, KC.TRNS, KC.TRNS, KC.TRNS, KC.TRNS, KC.TRNS, KC.TRNS, 
        KC.TRNS, KC.TRNS, KC.TRNS, KC.TRNS, KC.TRNS, KC.TRNS, KC.TRNS, KC.TRNS, KC.TRNS, KC.TRNS, KC.TRNS, KC.TRNS, KC.TRNS, KC.TRNS, KC.TRNS, KC.TRNS, KC.TRNS, 
    ]
];

if __name__ == '__main__':
    keyboard.go();

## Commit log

2025-02-02 Start of aniboard
    [aniboard.kicad_pcb, aniboard.kicad_sch]
2025-02-02 First three rows
    [aniboard.kicad_pcb, aniboard.kicad_sch]
2025-02-02 Keyboard layout
    [aniboard.kicad_pcb, aniboard.kicad_sch]
2025-02-02 Continue routing PCB
    [aniboard.kicad_pcb, aniboard.kicad_sch]
2025-02-05 Finish column routing
    [aniboard.kicad_pcb, aniboard.kicad_sch]
2025-02-06 More keyboard
    [MX v2.step, aniboard.kicad_sch]
2025-02-06 Added neopixels
    [aniboard.kicad_sch]
2025-02-06 Placed diodes
2025-02-06 Partial routing
    [aniboard.kicad_sch]
2025-02-12 Half done with routing
    [aniboard.kicad_sch, bom.csv, designators.csv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]
2025-02-12 Finish routing
    [aniboard.kicad_sch, bom.csv, designators.csv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]
2025-02-14 Finish PCB and top plate
    [DSA 1.25u.step, DSA 1.5u.step, DSA 1.75u.step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]
2025-02-14 Finish Plate
    [assembly.scad, case.scad, common.scad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]
2025-02-14 Finish case
    [assembly.scad, case.scad, case.stl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]
2025-02-15 Fix coplanar surfaces
    [case.scad, plate.scad]
2025-02-15 Assembly hotfix
    [assembly.scad, case.scad]
2025-02-15 Remove stuff
    [assembly.scad, case.scad, common.scad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]
2025-02-15 Fix render bug
    [assembly.scad, assembly.stl, common.scad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]
2025-02-16 Update pcb
    [bom.csv, case.stl, designators.csv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]
2025-02-16 Reexport using freecad
    [case.scad, case.step, case.stl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]
2025-02-16 Reroute and silkscreen
    [aniboard.kicad_sch]
2025-02-17 Last pass
    [aniboard.kicad_sch]
2025-02-20 Dual USB powah
    [aniboard.kicad_sch, bom.csv, designators.csv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]
2025-02-22 Change switches
2025-02-22 Fix tolarences
    [case.scad, case.step]
2025-02-24 Fix mounting hole error
    [aniboard.kicad_sch, bom.csv, designators.csv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]
2025-02-26 Update BOM
    [aniboard.kicad_sch, bom.csv, designators.csv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]
2025-03-07 Redesign v2!
    [acme_screws.scad, acrylic.dxf, aniboard.kicad_sch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]
2025-03-09 Fix case
    [aniboard.kicad_sch, bom.csv, bottom.step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]
2025-03-11 RX TX Breakout
    [aniboard.kicad_sch, bom.csv, designators.csv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]
2025-03-12 Modular case
    [bottom.step, case.3mf, plate.step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]
2025-10-25 Finally ordered
    [aniboard.kicad_sch, bom.csv, designators.csv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]
2025-10-31 Add ibom
    [aniboard.kicad_sch, case-CaseSlice.0.step]
